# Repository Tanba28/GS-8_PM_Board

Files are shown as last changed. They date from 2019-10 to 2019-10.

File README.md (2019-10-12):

# GS-8_PM_Board
GS-8 Power Management Board

Master project -> [project-arrows/GS-8](https://github.com/project-arrows/GS-8)

## Overview
 * GS-8電源管理基板
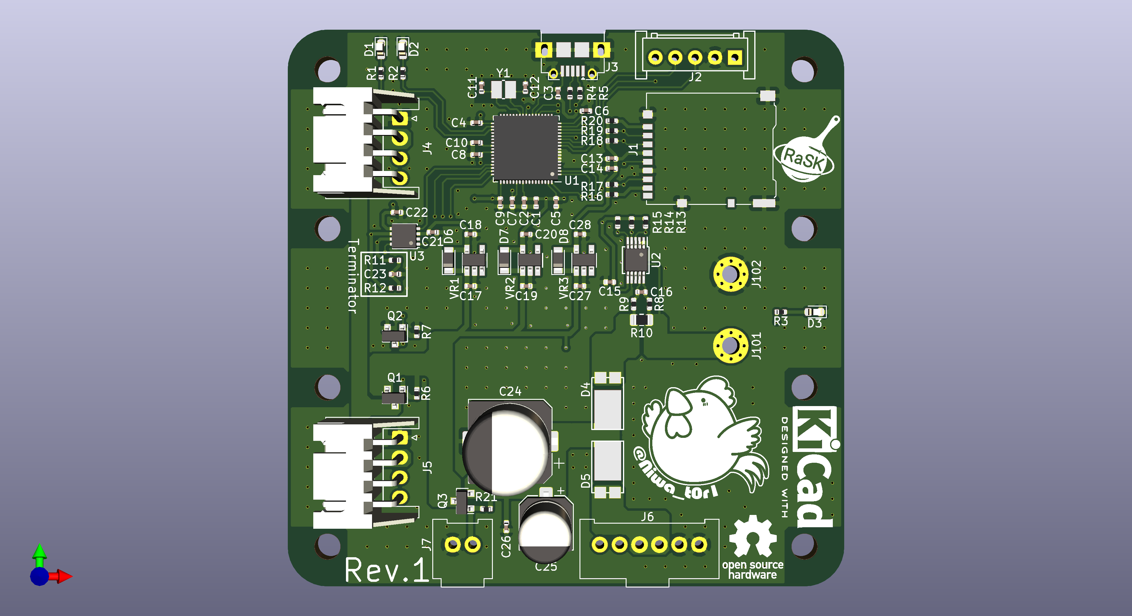
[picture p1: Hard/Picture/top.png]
top

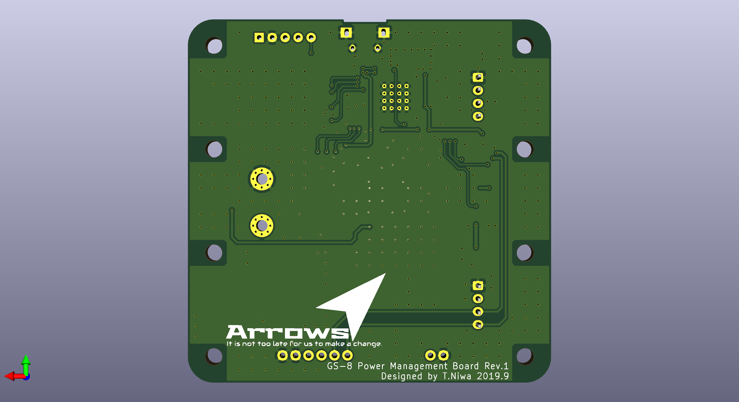
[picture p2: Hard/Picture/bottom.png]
bottom


## Role
 * 外部電源と内部電源の切り替えを行う。
 * 内部電源の電流・電圧を監視する。
 * 内部電源の電圧が規定値を下回った際にカットオフを行う。
 * CANバスを監視しロギングする。

## Link
 * [Tanba28/GS-8_PD_Board](https://github.com/Tanba28/GS-8_PD_Board)
 * [Tanba28/GS-8_Barometer](https://github.com/Tanba28/GS-8_Barometer)
 * [Tanba28/GS-8_Motion_Logger](https://github.com/Tanba28/GS-8_Motion_Logger)
 * [Tanba28/GS-8_Relay_Board](https://github.com/Tanba28/GS-8_Relay_Board)
 * [ringo156/GS-8_ACCLRM_Board](https://github.com/ringo156/GS-8_ACCLRM_Board)
 * [takamasavvv/RCT-X_Logger](https://github.com/takamasavvv/RCT-X-Logger)
 * [takamasavvv/RCT-X-Telemetry](https://github.com/takamasavvv/RCT-X-Telemetry)
 
## LICENSE
MIT License

Copyright (c) 2019 Tanba28

Permission is hereby granted, free of charge, to any person obtaining a copy
of this software and associated documentation files (the "Software"), to deal
in the Software without restriction, including without limitation the rights
to use, copy, modify, merge, publish, distribute, sublicense, and/or sell
copies of the Software, and to permit persons to whom the Software is
furnished to do so, subject to the following conditions:

The above copyright notice and this permission notice shall be included in all
copies or substantial portions of the Software.

THE SOFTWARE IS PROVIDED "AS IS", WITHOUT WARRANTY OF ANY KIND, EXPRESS OR
IMPLIED, INCLUDING BUT NOT LIMITED TO THE WARRANTIES OF MERCHANTABILITY,
FITNESS FOR A PARTICULAR PURPOSE AND NONINFRINGEMENT. IN NO EVENT SHALL THE
AUTHORS OR COPYRIGHT HOLDERS BE LIABLE FOR ANY CLAIM, DAMAGES OR OTHER
LIABILITY, WHETHER IN AN ACTION OF CONTRACT, TORT OR OTHERWISE, ARISING FROM,
OUT OF OR IN CONNECTION WITH THE SOFTWARE OR THE USE OR OTHER DEALINGS IN THE
SOFTWARE.

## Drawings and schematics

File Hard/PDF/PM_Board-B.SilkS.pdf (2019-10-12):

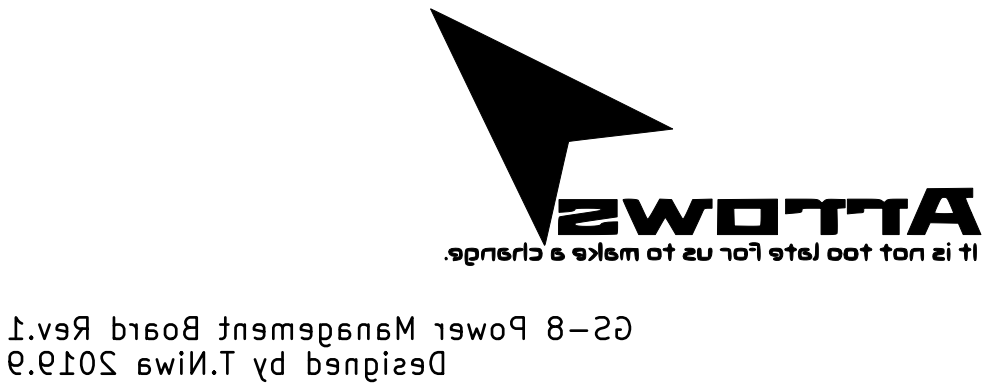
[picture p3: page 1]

GS-8 Power Management Board Rev.1 Designed by T.Niwa 2019.9

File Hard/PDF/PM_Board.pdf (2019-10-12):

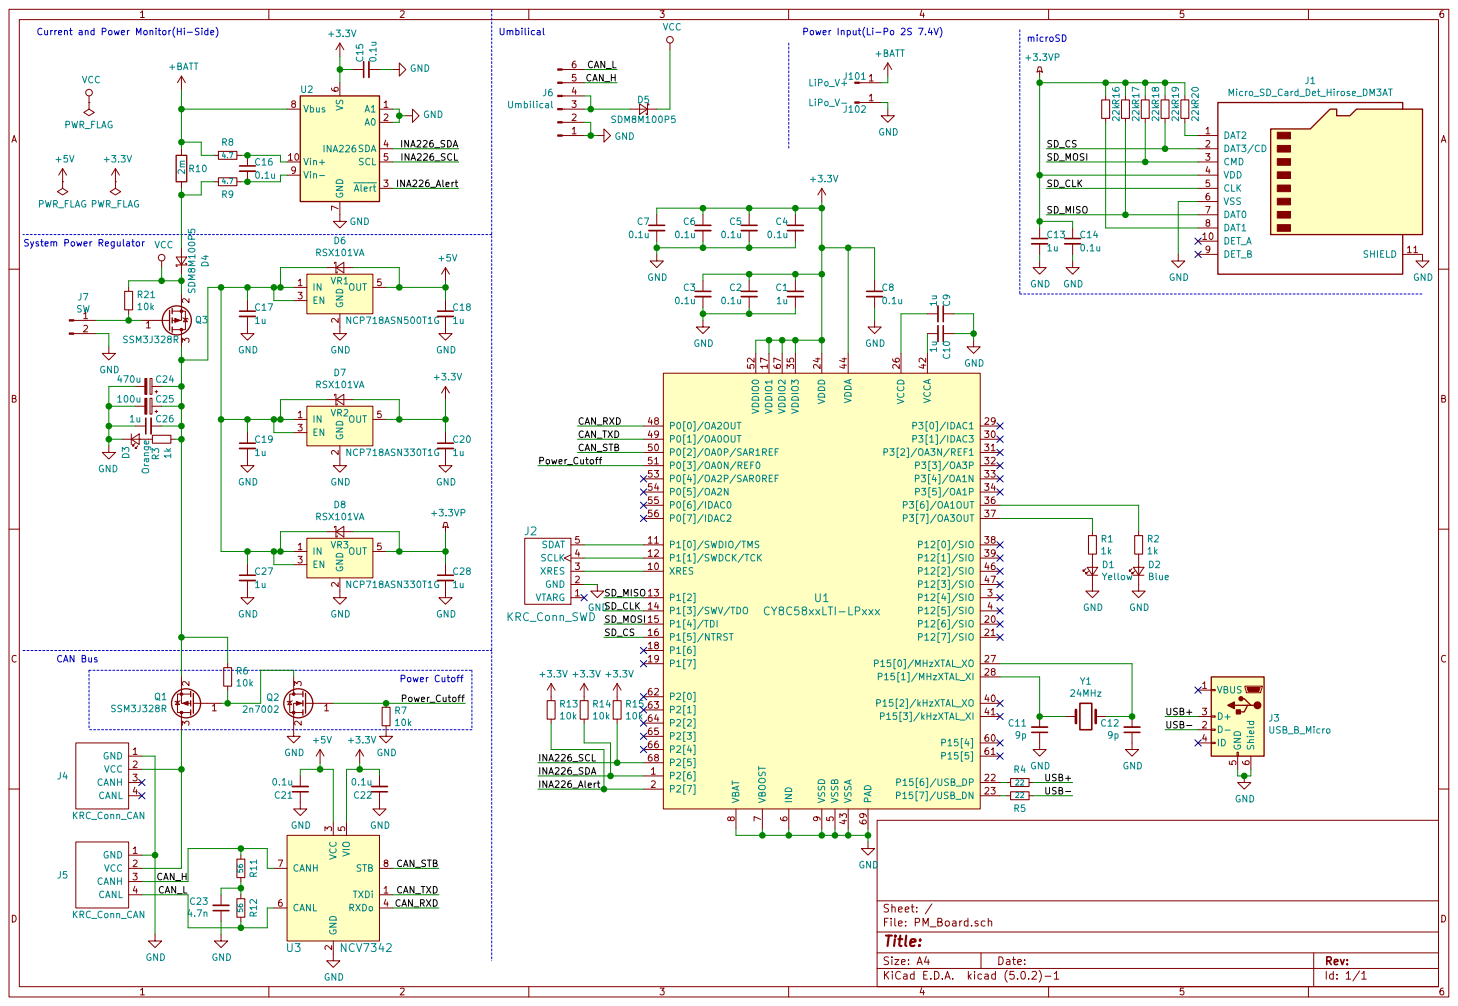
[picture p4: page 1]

File: PM_Board.sch Sheet: / GND

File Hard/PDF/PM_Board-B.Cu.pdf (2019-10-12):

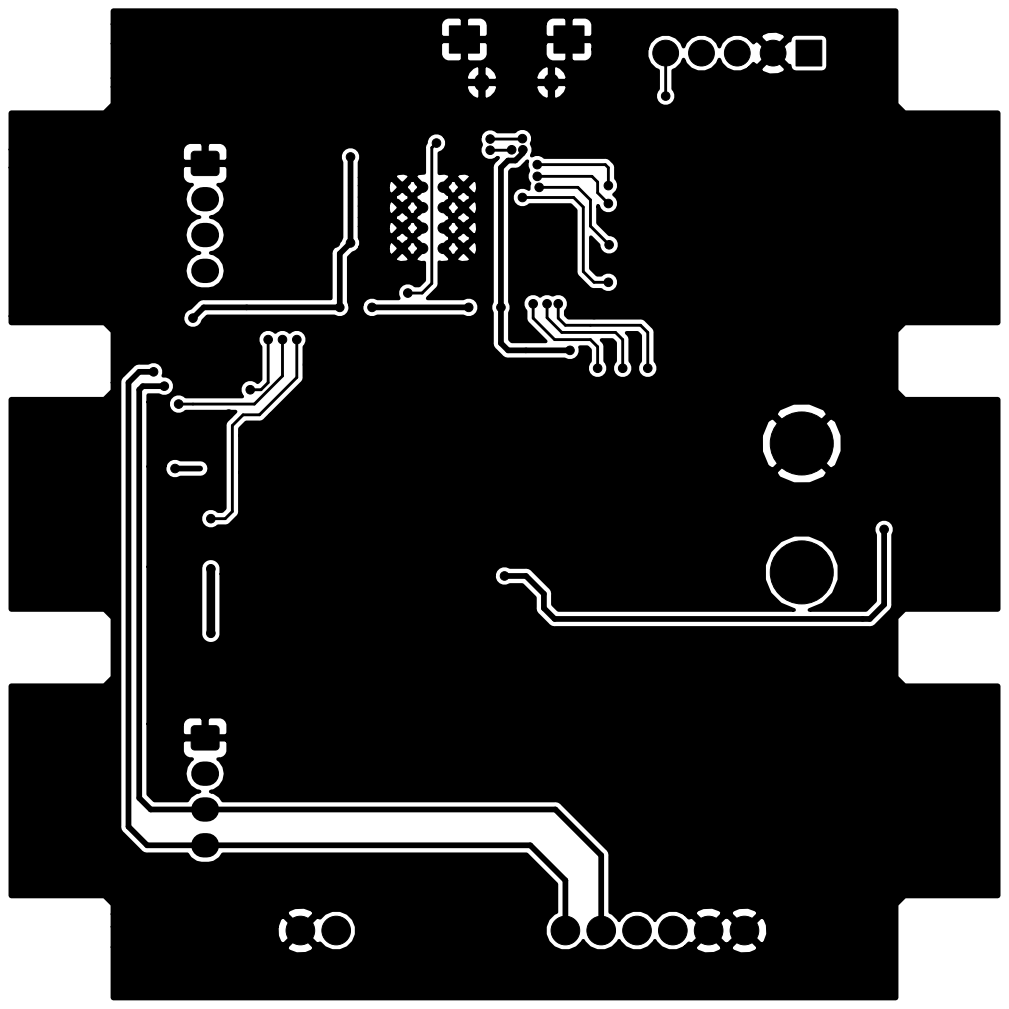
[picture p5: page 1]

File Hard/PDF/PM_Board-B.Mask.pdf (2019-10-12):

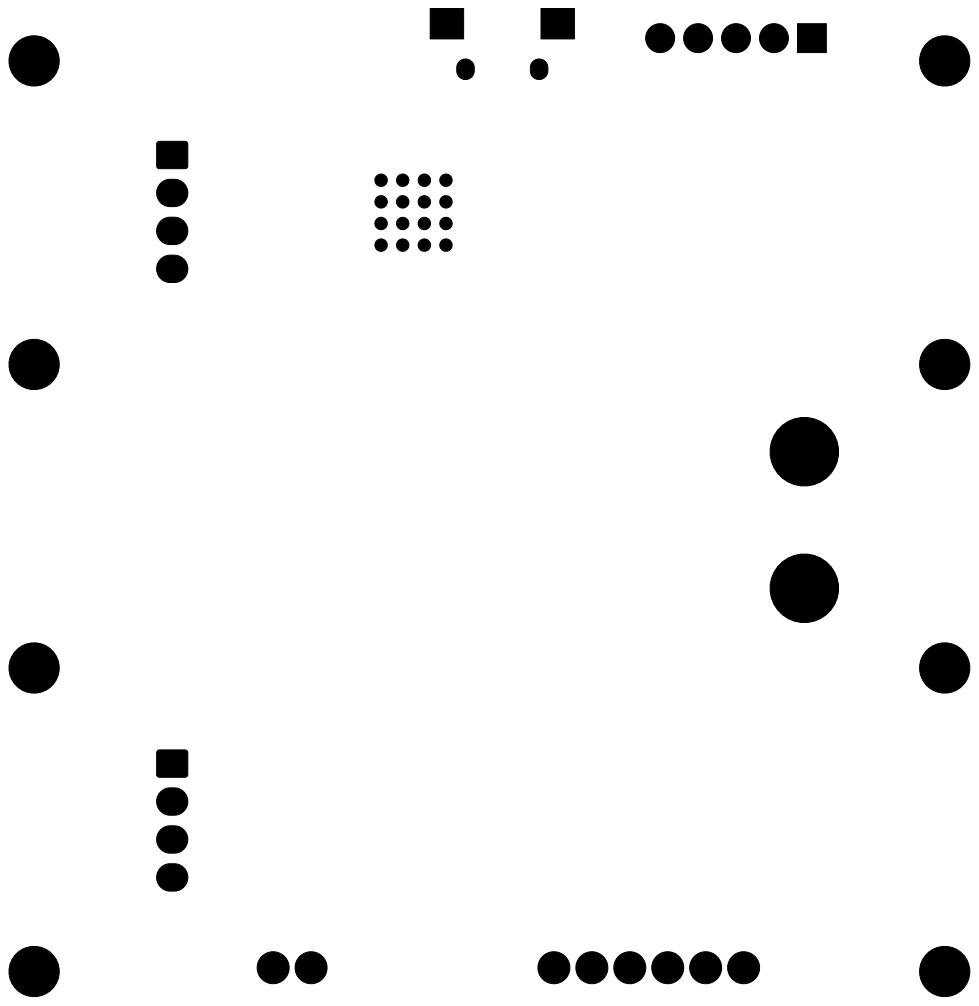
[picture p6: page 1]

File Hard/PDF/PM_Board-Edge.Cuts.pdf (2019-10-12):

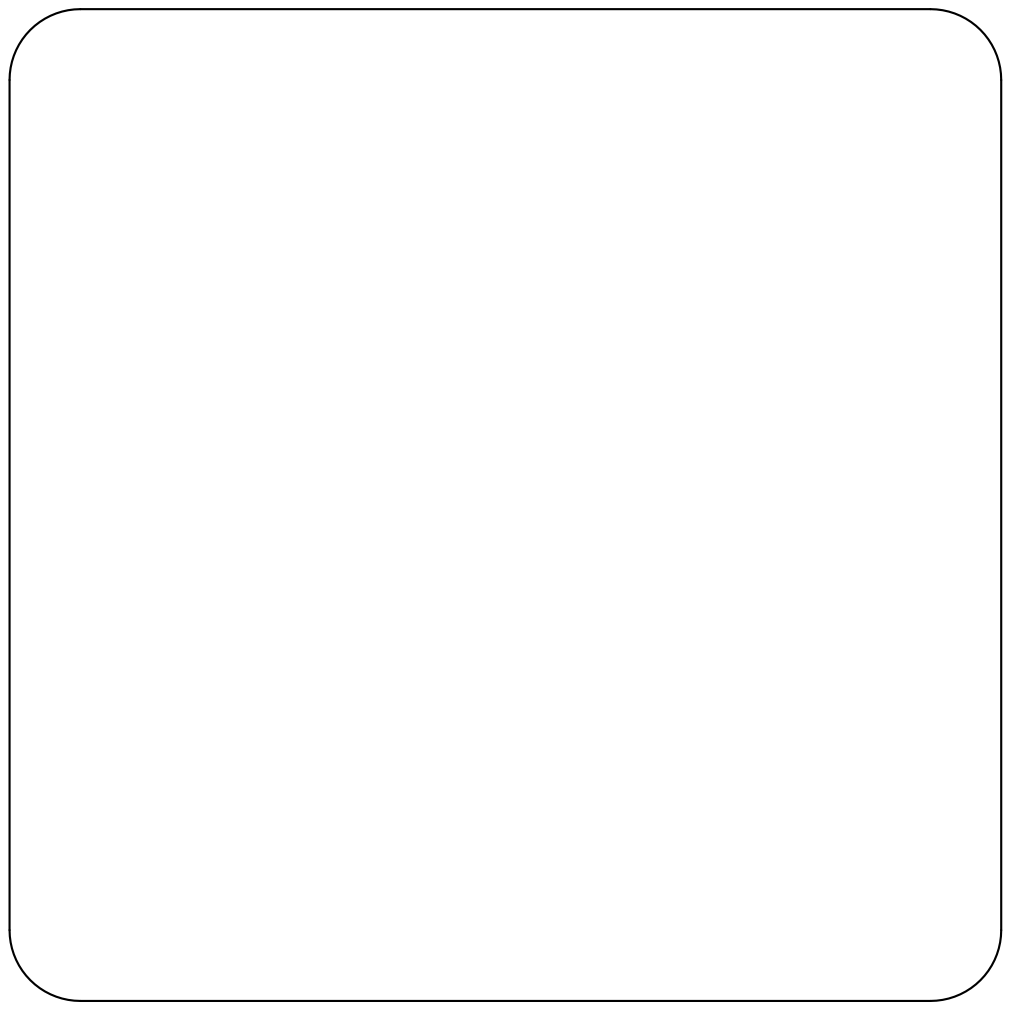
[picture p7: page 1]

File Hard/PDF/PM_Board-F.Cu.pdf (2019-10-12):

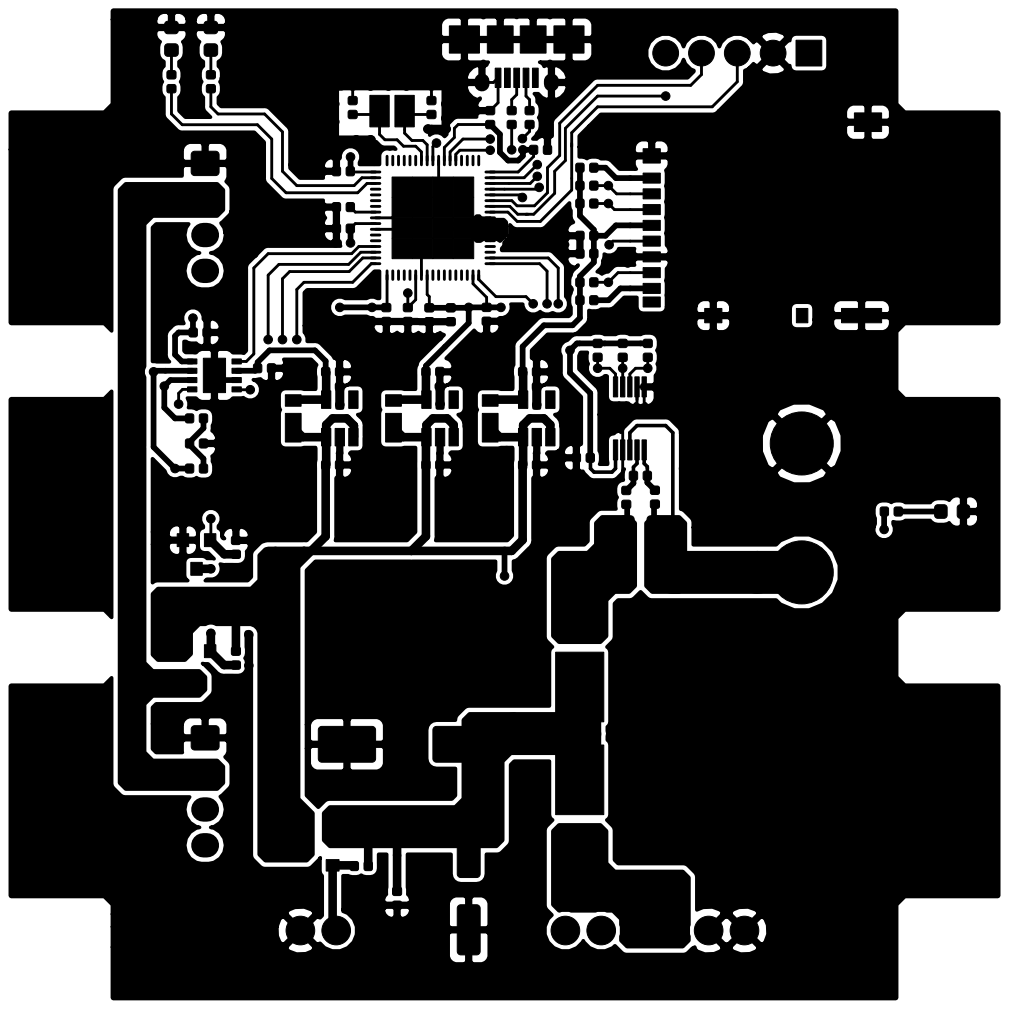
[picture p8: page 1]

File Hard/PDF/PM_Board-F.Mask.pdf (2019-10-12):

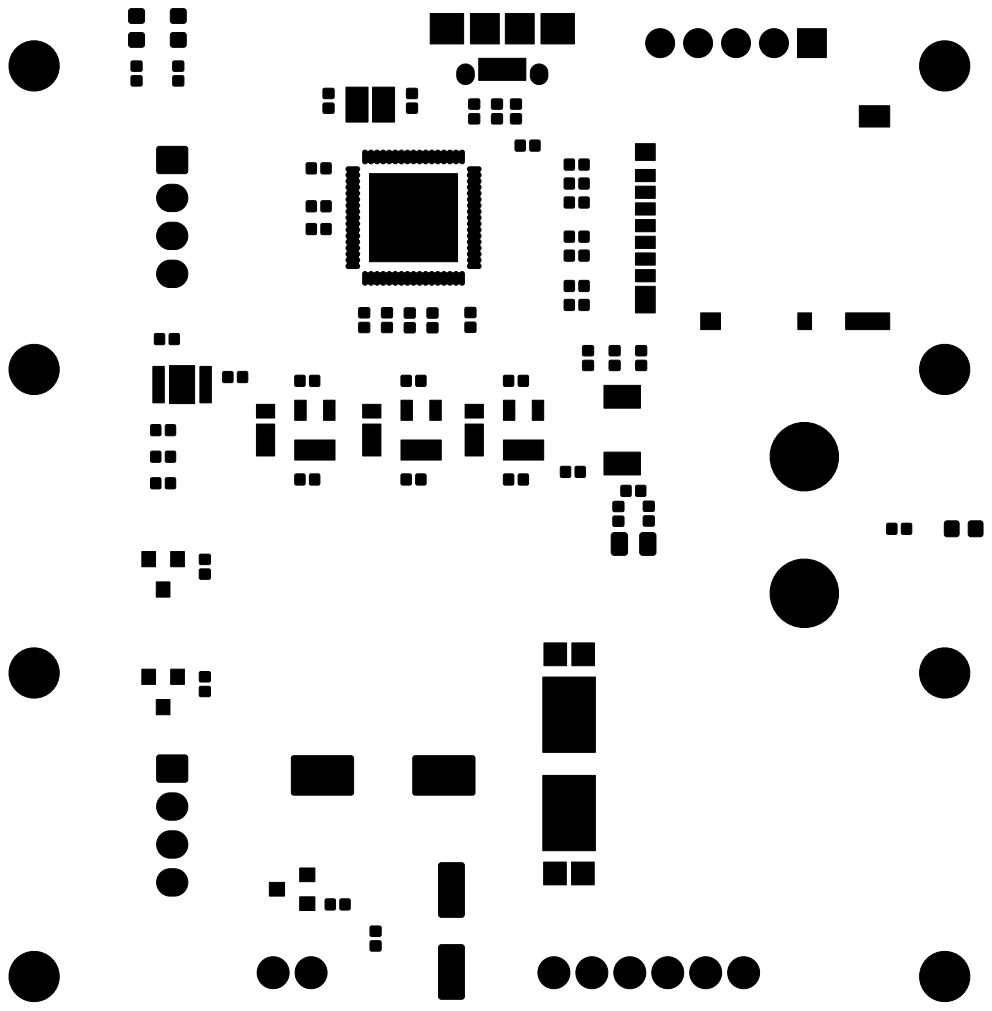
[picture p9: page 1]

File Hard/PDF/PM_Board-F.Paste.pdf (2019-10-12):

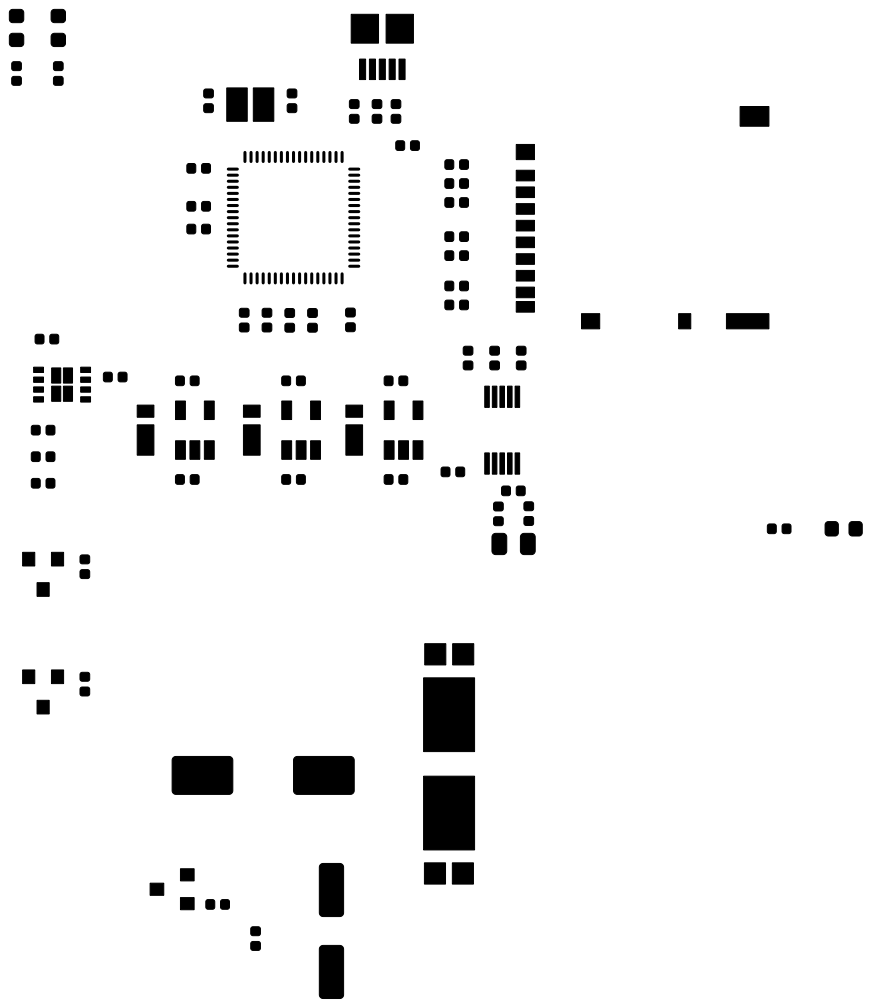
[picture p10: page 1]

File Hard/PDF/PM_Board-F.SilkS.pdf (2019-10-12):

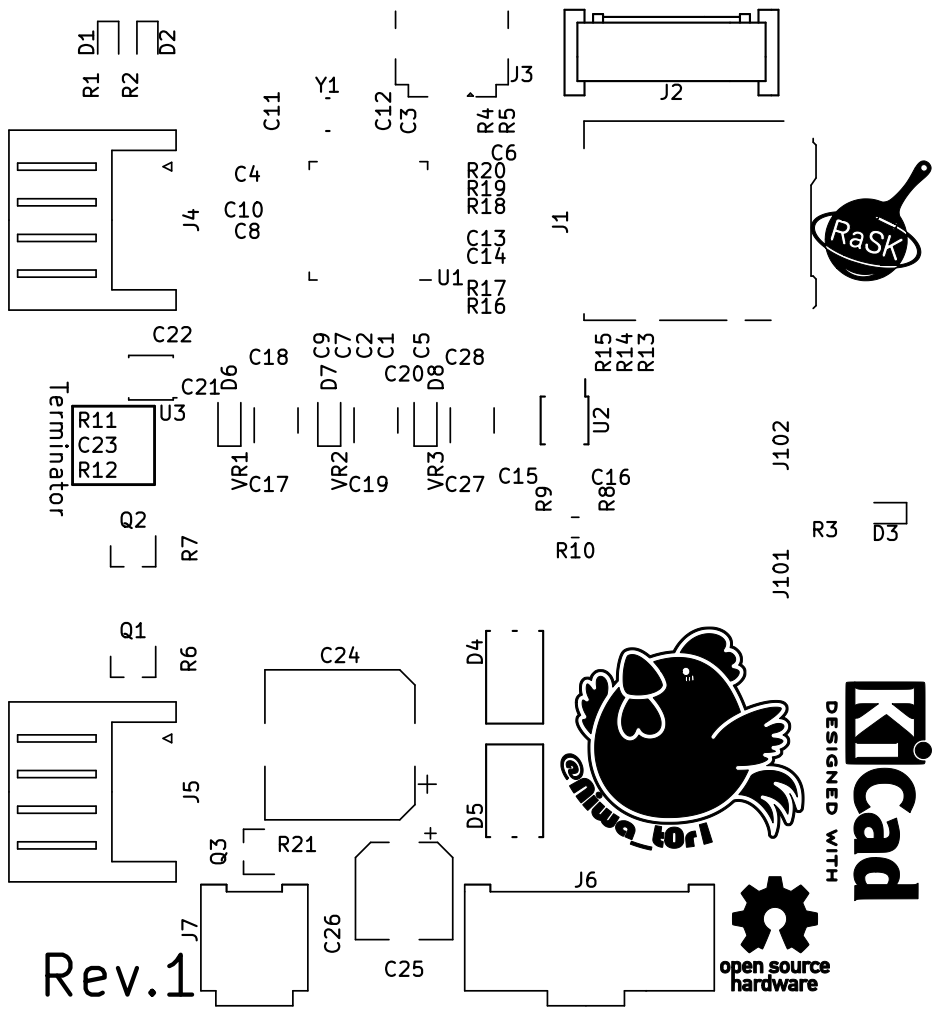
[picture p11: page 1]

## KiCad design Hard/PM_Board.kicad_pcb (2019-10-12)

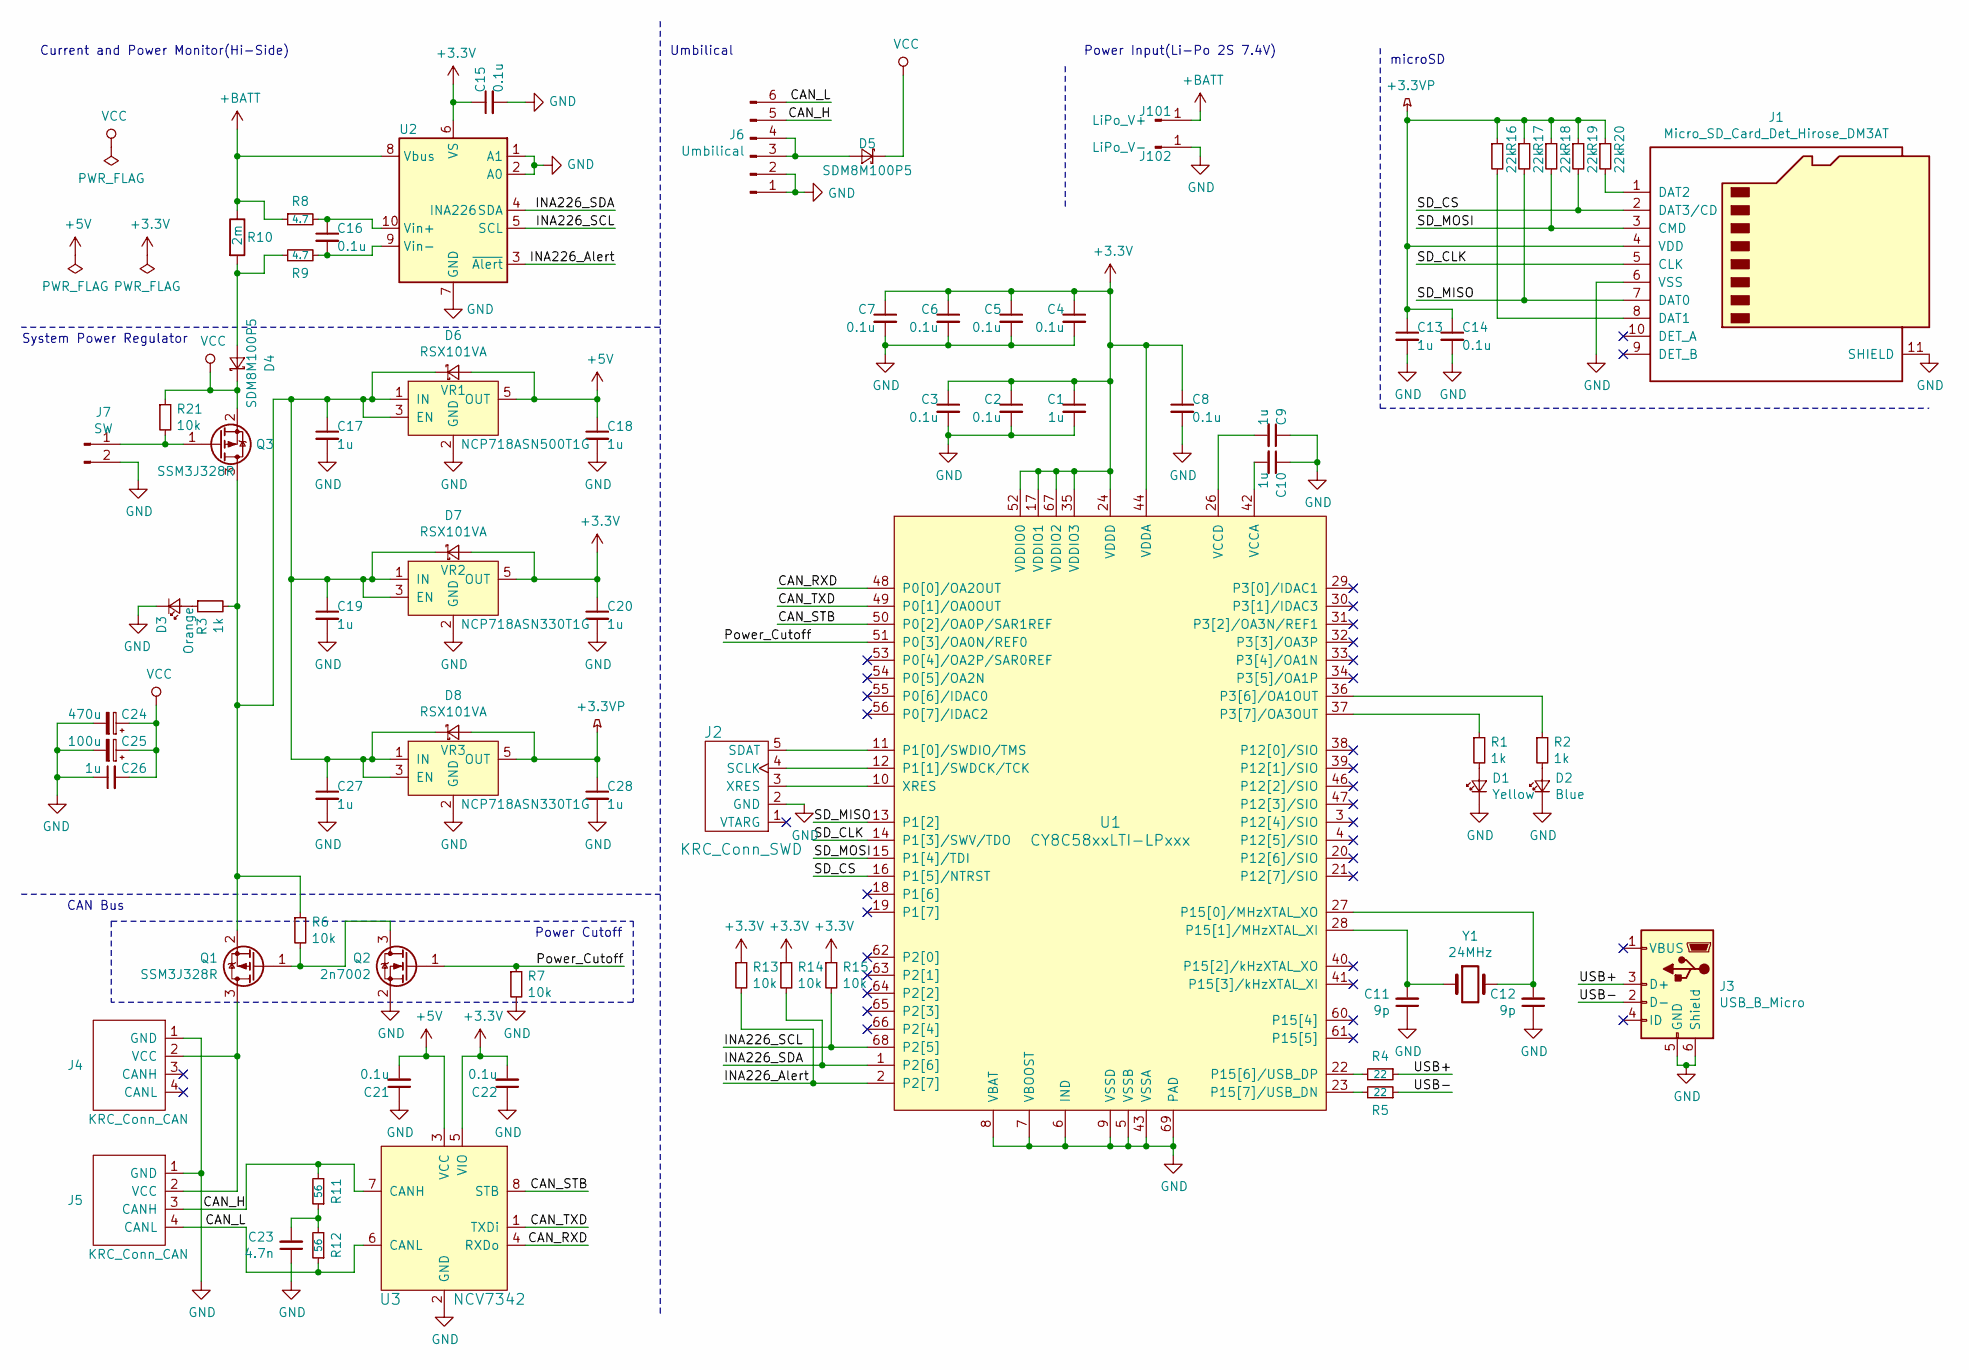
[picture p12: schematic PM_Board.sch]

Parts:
C1, C9, C10, C13, C17, C18, C19, C20, C26, C27, C28: 1u; C_0402_1005Metric; MPN GRM155R61E105KA12D
C2, C3, C4, C5, C6, C7, C8, C14, C15, C16, C21, C22: 0.1u; C_0402_1005Metric; MPN GRM155R62A104KE14D
C11, C12: 9p; C_0402_1005Metric; MPN GRM1555C1H9R0DA01D
C23: 4.7n; C_0402_1005Metric; MPN GRM155R71H472KA01D
C24: 470u; CP_Elec_10x10; MPN UWT1E471MNL1GS
C25: 100u; CP_Elec_6.3x7.7; MPN UWT1E101MCL1GS
D1: Yellow; LED_0603_1608Metric
D2: Blue; LED_0603_1608Metric
D3: Orange; LED_0603_1608Metric
D4, D5: SDM8M100P5; D_PowerDI5; MPN SDM8M100P5-13
D6, D7, D8: RSX101VA; D_TUMD2; MPN RSX101VAM-30TR
J1: Micro_SD_Card_Det_Hirose_DM3AT; microSD_HC_Hirose_DM3AT-SF-PEJM5; MPN DM3AT-SF-PEJM5
J2: KRC_Conn_SWD; JST_JQ_05JQ-BT_1x05_P2.5mm_Vertical; MPN 05JQ-BT
J3: USB_B_Micro; Hirose_ZX_ZX62D-B-5P8; MPN ZX62D-B-5P8(30)
J4, J5: KRC_Conn_CAN; JST_XH_S4B-XH-A_1x04_P2.50mm_Horizontal; MPN S4B-XH-A
J6: Umbilical; Hirose_DF1E_DF1E-6P-2.5DS_1x06_P2.5mm_Vertical; MPN DF1EC-6P-2.5DSA(35)
J7: SW; Hirose_DF1E_DF1E-2P-2.5DS_1x02_P2.5mm_Vertical; MPN DF1EC-2P-2.5DSA(35)
J101: LiPo_V+; MountingHole_2.2mm_M2_Pad_Via
J102: LiPo_V-; MountingHole_2.2mm_M2_Pad_Via
Q1, Q3: SSM3J328R; SOT-23; MPN SSM3J328R,LF
Q2: 2n7002; SOT-23; MPN 2N7002
R1, R2, R3: 1k; R_0402_1005Metric; MPN ERJ-2GEJ102X
R4, R5: 22; R_0402_1005Metric; MPN ERJ-2GEJ220X
R6, R7, R13, R14, R15, R21: 10k; R_0402_1005Metric; MPN ERJ-2GEJ103X
R8, R9: 4.7; R_0402_1005Metric; MPN ERJ-2GEJ4R7X
R10: 2m; R_0805_2012Metric; MPN PMR10EZPFV2L00
R11, R12: 56; R_0402_1005Metric; MPN ERJ-2GEJ560X
R16, R17, R18, R19, R20: 22k; R_0402_1005Metric; MPN ERJ-2RKF2202X
U1: CY8C58xxLTI-LPxxx; Cypress_QFN-68_EP_8x8_Pitch0.4mm; MPN CY8C5868LTI-LP039
U2: INA226; MSOP-10_3x3mm_P0.5mm; MPN INA226AIDGSR
U3: NCV7342; DFN-8-1EP_3x3mm_P0.65mm_EP1.55x2.4mm; MPN NCV7342MW3R2G
VR1: NCP718ASN500T1G; TSOT-23-5; MPN NCP718ASN500T1G
VR2, VR3: NCP718ASN330T1G; TSOT-23-5; MPN NCP718ASN330T1G
Y1: 24MHz; Crystal_Murata_XRCHA; MPN XRCHA24M000F0A01R0

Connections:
+3.3VP: C13.1, C14.1, C28.1, D8.2 (A), J1.4 (VDD), R16.1, R17.1, R18.1, R19.1, R20.1, VR3.5 (OUT)
+3V3: C1.1, C2.1, C3.1, C4.1, C5.1, C6.1, C7.1, C8.1, C15.1, C20.1, C22.2, D7.2 (A), R13.1, R14.1, R15.1, U1.17 (VDDIO1), U1.24 (VDDD), U1.35 (VDDIO3), U1.44 (VDDA), U1.52 (VDDIO0), U1.59 (VDDD), U1.67 (VDDIO2), U2.6 (VS), U3.5 (VIO), VR2.5 (OUT)
+5V: C18.1, C21.2, D6.2 (A), U3.3 (VCC), VR1.5 (OUT)
+BATT: J101.1, R8.1, R10.1, U2.8 (Vbus)
/CAN_H: J5.3 (CANH), J6.5, R11.2, U3.7 (CANH)
/CAN_L: J5.4 (CANL), J6.6, R12.1, U3.6 (CANL)
/CAN_RXD: U1.48 (P0[0]/OA2OUT), U3.4 (RXDo)
/CAN_STB: U1.50 (P0[2]/OA0P/SAR1REF), U3.8 (STB)
/CAN_TXD: U1.49 (P0[1]/OA0OUT), U3.1 (TXDi)
/INA226_Alert: R13.2, U1.2 (P2[7]), U2.3 (~Alert~)
/INA226_SCL: R15.2, U1.68 (P2[5]), U2.5 (SCL)
/INA226_SDA: R14.2, U1.1 (P2[6]), U2.4 (SDA)
/Power_Cutoff: Q2.1 (G), R7.1, U1.51 (P0[3]/OA0N/REF0)
/SD_CLK: J1.5 (CLK), U1.14 (P1[3]/SWV/TDO)
/SD_CS: J1.2 (DAT3/CD), R19.2, U1.16 (P1[5]/NTRST)
/SD_MISO: J1.7 (DAT0), R17.2, U1.13 (P1[2])
/SD_MOSI: J1.3 (CMD), R18.2, U1.15 (P1[4]/TDI)
/USB+: J3.3 (D+), R4.1
/USB-: J3.2 (D-), R5.1
GND: C1.2, C2.2, C3.2, C4.2, C5.2, C6.2, C7.2, C8.2, C9.1, C10.1, C11.1, C12.1, C13.2, C14.2, C15.2, C17.2, C18.2, C19.2, C20.2, C21.1, C22.1, C23.1, C24.2, C25.2, C26.1, C27.2, C28.2, D1.1 (K), D2.1 (K), D3.1 (K), J1.6 (VSS), J1.11 (SHIELD), J2.2 (GND), J3.5 (GND), J3.6 (Shield), J4.1 (GND), J5.1 (GND), J6.1, J6.2, J7.2, J102.1, Q2.2 (S), R7.2, U1.5 (VSSB), U1.6 (IND), U1.7 (VBOOST), U1.8 (VBAT), U1.9 (VSSD), U1.25 (VSSD), U1.43 (VSSA), U1.45 (VSSD), U1.58 (VSSD), U1.69 (PAD), U2.1 (A1), U2.2 (A0), U2.7 (GND), U3.2 (GND), U3.9, VR1.2 (GND), VR2.2 (GND), VR3.2 (GND)
unnamed: C9.2, U1.26 (VCCD), U1.57 (VCCD)
unnamed: C10.2, U1.42 (VCCA)
unnamed: C11.2, U1.28 (P15[1]/MHzXTAL_XI), Y1.1
unnamed: C12.2, U1.27 (P15[0]/MHzXTAL_XO), Y1.2
unnamed: C16.1, R8.2, U2.10 (Vin+)
unnamed: C16.2, R9.2, U2.9 (Vin-)
unnamed: C17.1, C19.1, C27.1, D6.1 (K), D7.1 (K), D8.1 (K), Q1.2 (S), Q3.3 (D), R3.2, R6.1, VR1.1 (IN), VR1.3 (EN), VR2.1 (IN), VR2.3 (EN), VR3.1 (IN), VR3.3 (EN)
unnamed: C23.2, R11.1, R12.2
unnamed: D1.2 (A), R1.2
unnamed: D2.2 (A), R2.2
unnamed: D3.2 (A), R3.1
unnamed: D4.2 (A), R9.1, R10.2
unnamed: D5.2 (A), J6.3, J6.4
unnamed: J1.1 (DAT2), R20.2
unnamed: J1.8 (DAT1), R16.2
unnamed: J2.3 (XRES), U1.10 (XRES)
unnamed: J2.4 (SCLK), U1.12 (P1[1]/SWDCK/TCK)
unnamed: J2.5 (SDAT), U1.11 (P1[0]/SWDIO/TMS)
unnamed: J4.2 (VCC), J5.2 (VCC), Q1.3 (D)
unnamed: J7.1, Q3.1 (G), R21.2
unnamed: Q1.1 (G), Q2.3 (D), R6.2
unnamed: R1.1, U1.37 (P3[7]/OA3OUT)
unnamed: R2.1, U1.36 (P3[6]/OA1OUT)
unnamed: R4.2, U1.22 (P15[6]/USB_DP)
unnamed: R5.2, U1.23 (P15[7]/USB_DN)
VCC: C24.1, C25.1, C26.2, D4.1 (K), D5.1 (K), Q3.2 (S), R21.1

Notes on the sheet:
Power Input(Li-Po 2S 7.4V)
Current and Power Monitor(Hi-Side)
System Power Regulator
CAN Bus
Power Cutoff
Umbilical
microSD

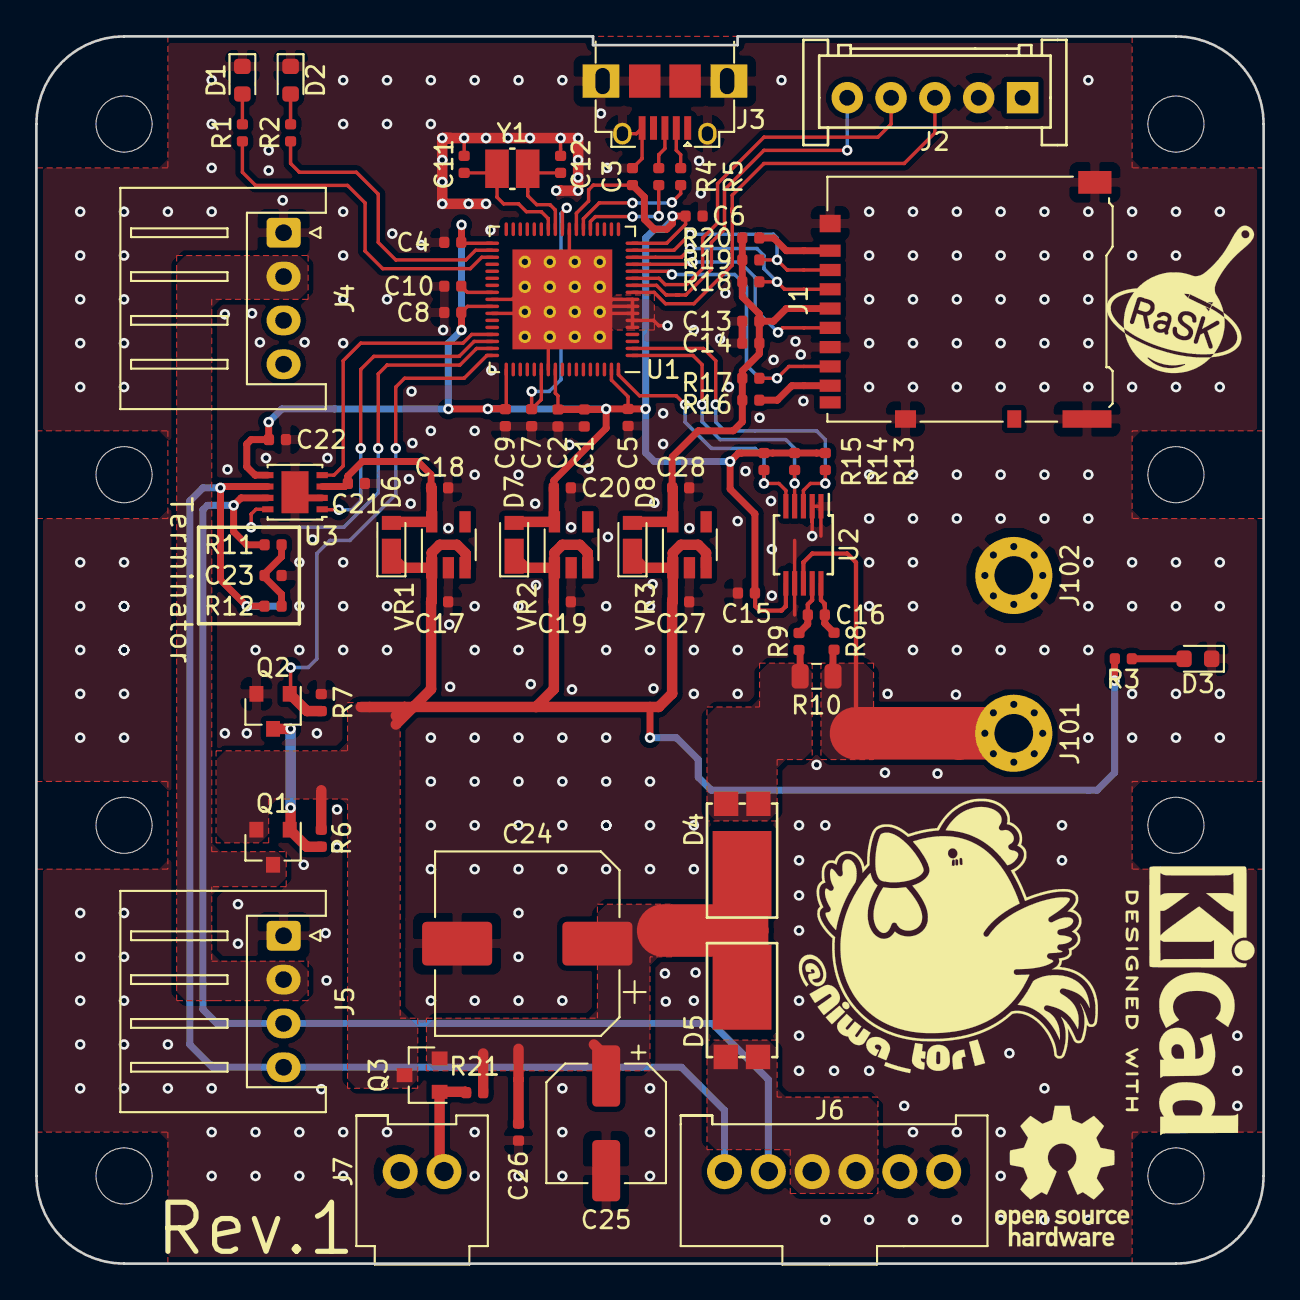
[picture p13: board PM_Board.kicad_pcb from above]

Board: 2 copper layers, 70.0 x 70.0 mm, 76 parts (0 on the bottom side), 46 nets.

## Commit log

2019-09-20 [add] プロジェクトファイル作成
    [PM_Board.kicad_pcb, PM_Board.sch]
2019-09-20 [add] マイコン・SD・電源周りを配置
    [PM_Board.sch]
2019-09-21 [add] フットプリントの割当を完了
    [PM_Board.sch]
2019-09-21 [add] PCBの基板外形を作った
    [PM_Board.kicad_pcb, PM_Board.sch]
2019-09-24 [add] 電源系のダイオードをアンビリカル側にも追加
    [PM_Board.sch]
2019-09-24 [add] 部品配置仮完了
    [PM_Board.kicad_pcb, PM_Board.sch]
2019-09-24 [update] ライブラリのライセンス表記更新
2019-09-24 [update] カットオフ用のFETをPchに変更してハイサイドへ移動
    [PM_Board.sch]
2019-09-24 [update] ミスを修正
    [PM_Board.sch]
2019-09-24 [add] 配線中だよ
    [PM_Board.kicad_pcb, PM_Board.sch]
2019-09-25 [add] 基板完成
    [PM_Board.kicad_pcb, PM_Board.sch]
2019-09-25 [add] pdf、SVGを追加
    [PM_Board.kicad_pcb]
2019-09-29 [add] 逆流防止用ダイオードを追加
    [PM_Board.sch]
2019-10-02 [update] パターンを編集完了
    [PM_Board.kicad_pcb, PM_Board.sch]
2019-10-02 [update] アンビリカルをDF1Eに変更
    [PM_Board.kicad_pcb, PM_Board.sch]
2019-10-02 [update] 部品の干渉を修正
    [PM_Board.kicad_pcb]
2019-10-04 [update] SDカード用のLDOを追加
    [PM_Board.kicad_pcb, PM_Board.sch]
2019-10-09 [add] ダイオードの選定を変更。PchMOSFETの選定を変更。パターンを引き直し。ガーバ出力
    [PM_Board-B.Cu.gbl, PM_Board-B.Mask.gbs, PM_Board-B.Paste.gbp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]
2019-10-09 [update] パスコンの位置を変更
    [PM_Board-B.Cu.gbl, PM_Board-B.Mask.gbs, PM_Board-B.Paste.gbp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]
2019-10-12 [add] USBに切り欠きを追加.ガーバー出力
    [PM_Board-B.Cu.gbl, PM_Board-B.Mask.gbs, PM_Board-B.Paste.gbp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]
2019-10-12 [update] READMEを整備
    [PM_Board.sch]
